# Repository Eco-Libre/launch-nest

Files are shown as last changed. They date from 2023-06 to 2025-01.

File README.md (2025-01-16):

# Eco-Libre Launch-Nest

This repo contains designs for a 5-story building that's designed to house 30 people in a small, off-grid community.

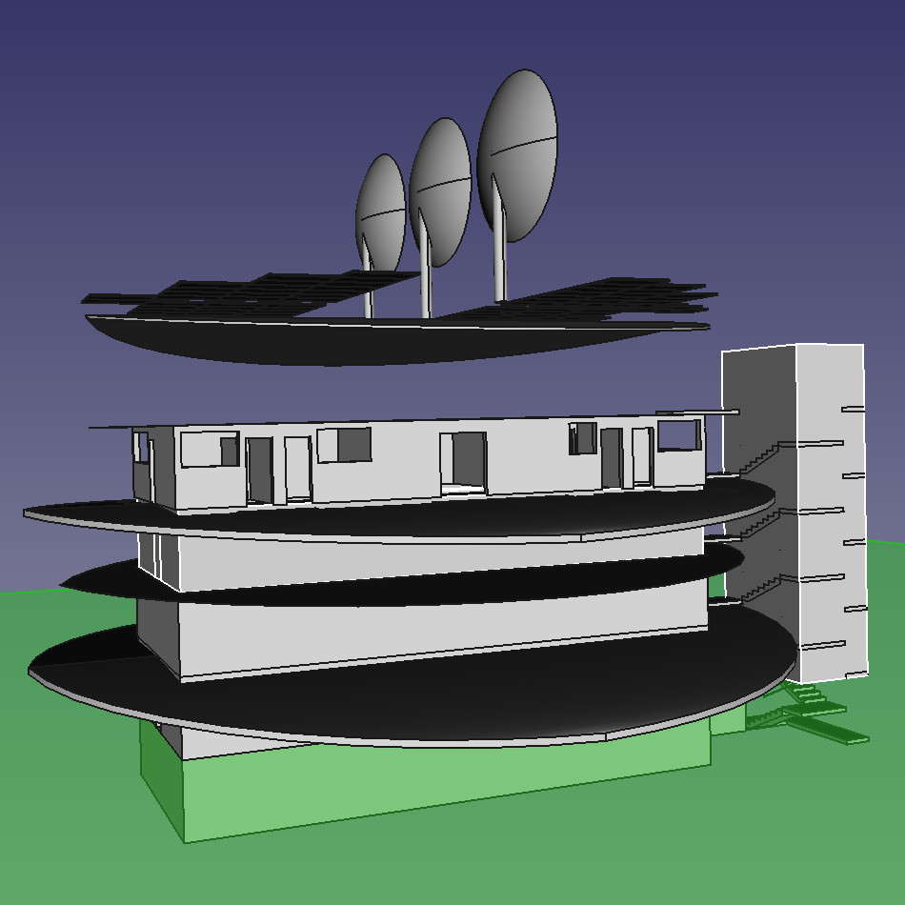
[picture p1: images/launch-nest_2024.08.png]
Screenshot of CAD file
</a>

The structure itself is 18 meters x 7 meters and has 5 stories of walled living space (630 sq meters). This does not include the solar energy rooftop, 5th floor terrace, wrap-around balcony, or firewalled stairwells.

## Basement

1. Food storage
1. Small urine sump tank & pump
1. Event Room (Theater, Presentation, Dance, Party, etc)
1. Recording Studio

## 1st Floor

1. Kitchen
1. Barrier-free bedroom (6 beds)
1. Shower room
1. Laundry Room
1. Medium-sized thermal salt tank
1. Large urine WC

## 2nd Floor

1. 2x Bedrooms (4 beds each = 8 people)
1. Ramp to terrace
1. Covered outdoor bicycle parking on terrace
1. Hot Water Tank (directly above showers)
1. Medium-sized thermal salt tank (next to hot water tank)
1. Small Urine WC
1. Telecommunications & Server Room
1. 1x meeting room
1. 1x large meeting room
1. Lockers and couches

## 3nd Floor

1. 2x Bedrooms (4 beds each = 8 people)
1. Large Urine WC
1. Library (~12 hot desks)
1. 2x Meeting Rooms

## 4th Floor

1. 2x Bedrooms (4 beds each = 8 people)
1. Small Urine WC
1. 1x Meeting Room
1. Indoor Coworking Space (~20 hot desks)
1. Snack and Coffee Bar
1. small-sized thermal salt tank

## 5th Floor

1. Open-Air Terrace
1. Projector & Presentation Space
1. Battery & Transformer Electrical Room
1. Large Thermal Salt Tank
1. Ground-Water Tank
1. Rain-Water Tank
1. Filtered Drinking-Water Tank
1. Primary Urine-Water Tank
1. Sun Room
1. Clothes Drying Area

## Rooftop

1. Parabolic Solar Concentrators
1. Solar Photovoltaic Array
1. Sloped, Steel-reinforced concrete grid
1. Sunroof grid
1. Large overhang of transparent polycarbonate panels
1. Small pressurized water tank (and pump) for washing solar equipment

# License

Copyright (C) 2023 Michael Altfield and the Eco-Libre Team

The contents of this repo are under the GPL version 3 or later.
In addition, any content other than code can also be used, at your
choice, under CC-BY-SA version 4.0.

This program is free software: you can redistribute it and/or modify
it under the terms of the GNU General Public License as published by
the Free Software Foundation, either version 3 of the License, or
(at your option) any later version.

This program is distributed in the hope that it will be useful,
but WITHOUT ANY WARRANTY; without even the implied warranty of
MERCHANTABILITY or FITNESS FOR A PARTICULAR PURPOSE.  See the
GNU General Public License for more details.

You should have received a copy of the GNU General Public License
along with this program.  If not, see <http://www.gnu.org/licenses/>.

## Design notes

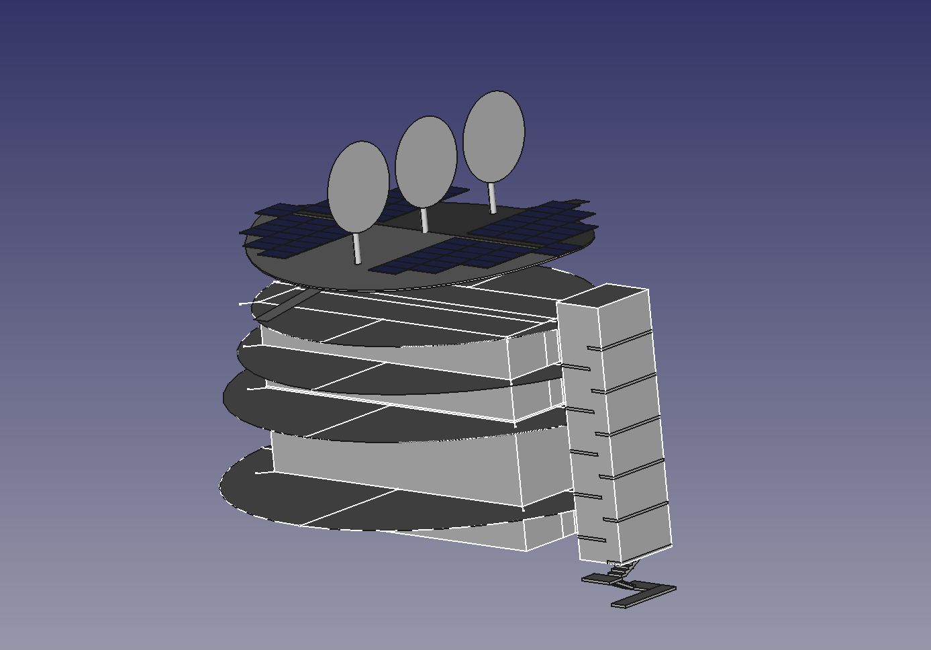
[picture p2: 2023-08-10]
images/launch-nest_2023.08.png

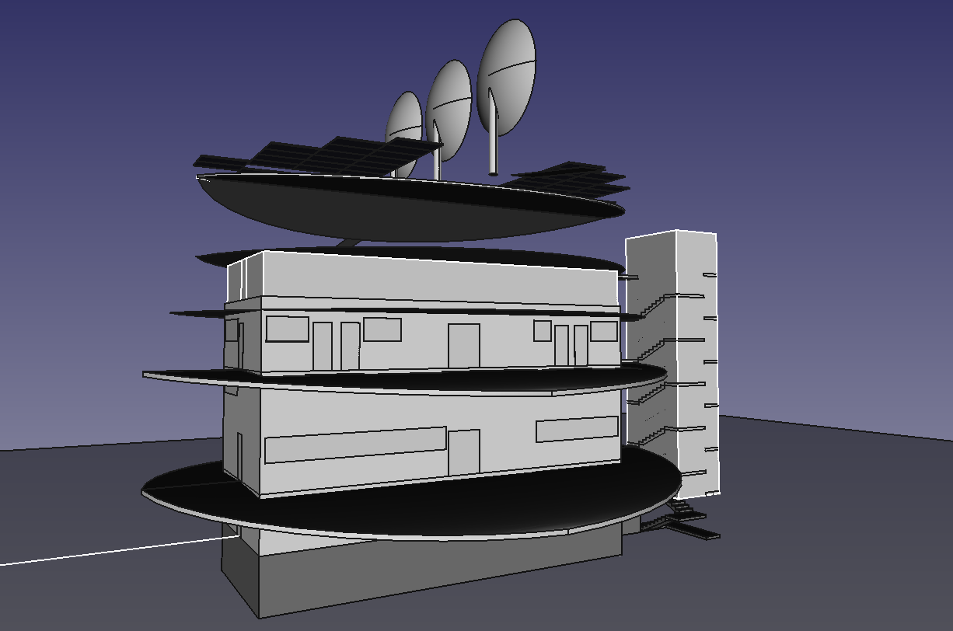
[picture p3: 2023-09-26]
images/launch-nest_2023.09.png

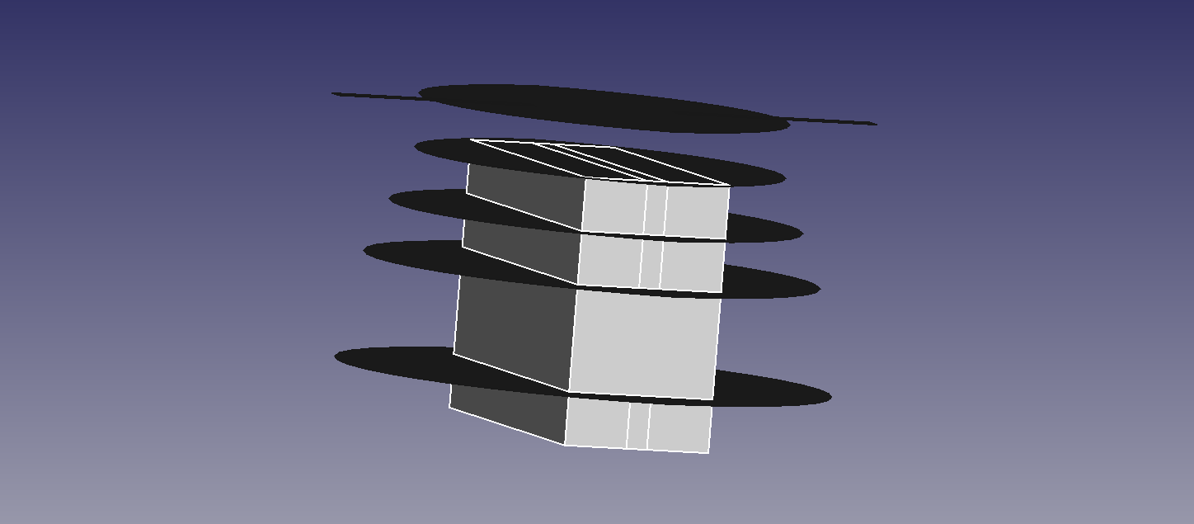
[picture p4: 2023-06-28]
images/launch-nest_2023.06.png

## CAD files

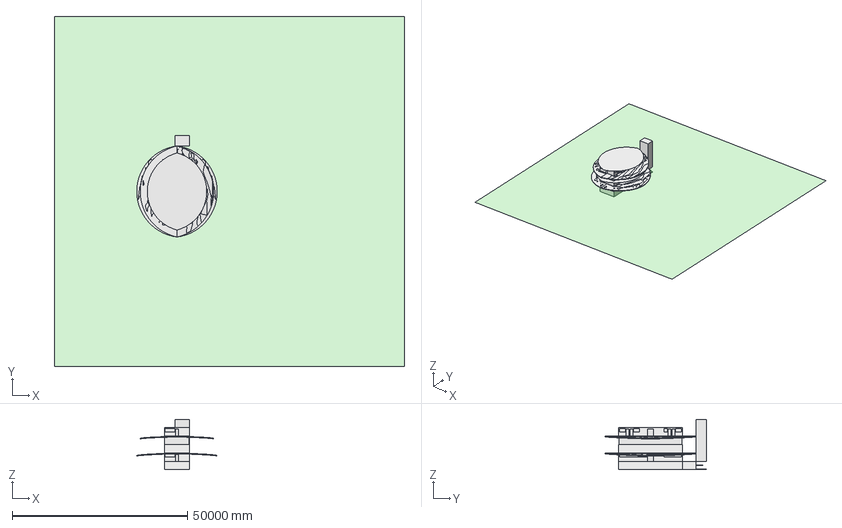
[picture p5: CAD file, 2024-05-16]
launch-nest.FCStd
100000.0 x 100000.0 x 14400.0 mm
floor 2 walls
left terrace surface 2
right terrace surface 2
left terrace
right terrace
floor 4 walls
right terrace surface 4
left terrace surface 4
left terrace 4
right terrace 4
floor 3
floor 3 terrace
floor 5 terrace
Wall
ground surface
rear stair landing
rear stair half landing
stairwell L-landing
rear stairwell exterior wall
rear door 1
front door 1
right door 1 main
left door 1 main
left window 1a
left window 1b
right window 1a
right window 1b
front widow 1
rear window 1
basement walls
rear door 4
front door 4
bedroom doors 4D
bedroom doors 4C
bedroom doors 4A
bedroom doors 4B
right door 4
left door 4
rear window 4
right window 4D
right window 4A
right window 4C
left window 4B
left window 4A
left window 4C
left window 4D
right window 4B
front window 4

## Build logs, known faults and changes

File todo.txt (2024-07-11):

TODO:

 * add "events" space to basement
   - delete two of the 6m x 3m rooms
   - one 6m x 3 room will be storage
   - one 6m x 3 room will be recording studio
   - get rid of the other 2 rooms (keep the two that are under the 1st floor bedroom)
   - this will provide a space for events with loud music that's underground, so it will muffle the noise

 * increase storey height
   - Noise isolation between floors can only achieve so much through thick concrete slabs. Specifically STS (airborne sound) can be dampened between floors with a thick slab, but IIC (impact sound) needs physical isolation. This means building a floor above the floor (eg a raised bamboo floor whoose posts sit on rubber (sound-isolation) footings on-top of the concrete floor slab.
    * See https://engineering.stackexchange.com/questions/60671/how-to-build-apartment-floors-ceilings-to-not-transfer-sound/60672
   - We need to figure-out the thickness of the concrete slab + the (bamboo?) floating floor above it + a buffer on the ceiling for piping, duct work, light fixtures, or a (sound isolation) drop-ceiling
    * See https://engineering.stackexchange.com/questions/60825/are-mutli-story-structure-slabs-poured-on-center
   - The minimum height of clearance from the top of the floating floor to the bottom of any ceiling infrastructure should be 2.4 meters. Currently the wall height of each storey is only 2.4 meters -- which doesn't even take into account the slab thickness. So we may end-up with 3-meter wall-height.

 * add stairwells on either side
    - I think I should make these entirely outside the existing structure, located on either end of the short sides of the structure. This will save space inside, be a safer fire exit, allow us to add an elevator on the outside along the stairwell, and it would allow us to re-use the same stairwell for the other buildings that would come perpendicular to this one
    - also, I think we should only have the stairwells go up to the 6th floor. We can have just a ladder and hatch to get from the 6th floor to the rooftop. This will reduce materials and prevent casting shade on our solar equipment on the rooftop

 * finish roof
    - make the steel-reinforced-concrete rooftop have a slight slope
    - add gutters
    - add transparent roofing around the perimeter
    - convert solid roof to grid of steel-reinforced concrete walkways
    - add parabolic dishes where the grid is
    - add transparent roofing where the gird is not

 * add different sizes

	Pico (6-person) (the smallest Eco-Libre Launch-Nest): it's just the basement and 1st floor, with ability to add another floor later

	Nano (14-person): Adds the second floor with two additional bedrooms

	Micro (30-person): Adds the rest of the structure

	Milli (150-person): Adds two more launch nests on either side, plus another two running parallel 60 meters away

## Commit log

2023-06-25 2023-06-25: After spending too much time dreaming and writing-out ideas in Zim, I'm finally creating the first "housing" structure in zim.
    In this first commit I've added a spreadsheet that determines the width and height and number of bedrooms. The idea is that it'll be shaped rectangular like an apartment. I don't want to make it wider because I want every room to have balcony access. The structure will grow to 6 stories, and if that's not enough, I'll add 3x more around a courtyard. Then that 4x design can be duplicated to form blocks and streets, if needed.
    Anyway, all I have now are the 4 external walls and a hallway. Now I need to add some room dividers. Then I want to experiment with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
    [house2.FCStd]
2023-06-27 fixed constraints on sketch and adjusted floor height to come from spreadsheet (with new alias for ceiling height)
    [house2.FCStd]
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2023-06-28 made the 5th floor and the terraces going-up slightly smaller
    I'm thinking that the actual roof of every terrace will be equal, but the floor will end shorter as it gets higher. The floor will be extended (after a railing) by transparent roofing. This will allow more light into the lower terraces without getting rain on the edges (where we may like to place tables & chairs)
    [house2.FCStd]
2023-06-28 added roof.
    Actually, I realized that I don't need clear roofing panels on every floor. I just need to have this last roof layer extend-out an overhang that's larger than the second-floor terrace. I don't think 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
    [house2.FCStd]
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2023-06-28 added a 1-meter-wide "roof walkway" I might remove this, instead opting for a smaller beam. Anyway, this currently shows how far out I plan to build the roof overhang that will use transparent roofin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
    [house2.FCStd]
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2023-06-28 began slicing-up the roof into triangles with the hope of making it sloped. First (North-West) triangle is done with this commit
    [launch-nest.FCStd]
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2023-06-28 created sketch of just NW roof triangle
    I couldn't find a way to go from a surface to a part. This is an issue because a surface doesn't appear to have a thickness and it can't be manipulated in three dimensions. I need one point of the triangle to be shifted-up in the z-plane
    [launch-nest.FCStd]
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2023-06-28 added last triangle, but it's shit
    I couldn't figure out how to draw a sketch in three dimensions. What I really need is to just move the vertex where all the triangeles meet up by, say, 0.5 meters. That's it. But all I could do was d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
    How the heck do I just modify the z-coordinates of one vertex in a sketch on the xy plane?
    [launch-nest.FCStd]
2023-06-28 tried a cone for the roof, but that won't work because the sides are uneven. I scraped the cone and the triangles. What I really need is a 4-sided tetrahedron (disphenoid)
    [launch-nest.FCStd]
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2023-06-29 added a ridgeline for the rooftop slope, which will have a 1 meter rise. Across a run of 17 meters / 2 = 8.5 meters, that's a 6.71 degree slope, which should be good
    [launch-nest.FCStd]
2023-06-29 ok, holy shit, I figured out how to sketch in 3 dimensions..sort-of
    This commit adds a sloped plane that runs from the previously flat rooftop floor up to a ridgeline that was floating 1 meters above it, straddling the center.
    Well, it's just a triangle for now because it was easier than an arch. I'll do the arch next.
    Basically the way this worked is that I took my existing sketch of the roottop floorplan on the xy plane, then I created a *new* sketch that hovered a single ridgeline *above* that one, also on the x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
    At this point, the new sketch on the xy plane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
    [launch-nest.FCStd]
2023-06-29 drafted a wire around the arch for the other side of the rooftop.
    I had to use the "upgrade" button to combine the arch and the ridgeline together. That worked, but for some reason it isn't filled-in like the triangle
    [launch-nest.FCStd]
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2023-06-29 added 315W 315W 315W 315W 315W 315W 315W 315W 315W 315W 315W 315W 315W 315W 315W 315W 315W 315W 315W 315W 315W 315W 315W 315W 315W 315W 315W 315W 315W 315W 315W 315W 315W 315W 315W 315W 315W 315W 315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
    [launch-nest.FCStd]
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2023-06-29 added 36x solar cells on the rear half of the roof. At 315W per panel, that's 1.11.340 kW. We can mirror these arrays on the front half of the roof for a total of 22.680 kW, which meets our target of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
    And there's still space in the middle of the roof for our solar concentrators. Hopefully we can fit four 16 sq meter scheffler dishes, which are 5 meter by 4 meter.
    * https://www.sciencedirect.com/science/article/abs/pii/S2451904918302634
    [launch-nest.FCStd]
2023-06-29 added solar concentrator, mirrored solar cells, and somehow lost one row of solar panels (?)
    [launch-nest.FCStd]
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2023-06-29 added the 16 square meter Scheffler concentrator. The size of the dish in freecad is 5 meters in diameter, but it should actually be 5 meters in one axis and 4 meters in another axis. So they're a bi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
    Obviously the focal point will be aimed at a collection chamber, which is absent. But this roughly shows us that we can fit three dishes. They'll shade the PV rays, but I don't see a way around that 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
    [launch-nest.FCStd]
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2023-06-29 added new sketch just for the roof perimeter based off of the main roof sketch, which we'll position on a different z-axis so we can draft support beams at a slope
    [launch-nest.FCStd]
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2023-06-29 lowered the roof overhang from the roof by 0.6 meters. This will give the slope 6.843 degrees on the 5 meter run and 7.595 degrees on the 4.5 meter run. That's slightly more than the rooftop, which h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
    [launch-nest.FCStd]
2023-06-29 added a line for the start of the roof's overhang walkway, so I can attach to it in draft workbench
    [launch-nest.FCStd]
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2023-06-30 added a single stair
    after some research, it looks like the Irish government defines the "optimum" emergency (fire) egress stairwells of having a width of 1 meter, a rise of 150 mm, and a going/run of 300mm.
    * https://www.gov.ie/pdf/?file=https://assets.gov.ie/100533/6926c022-4a80-4a05-8a55-dda6347bdaca.pdf#page=null
    * https://www.gov.scot/publications/building-standards-technical-handbook-2020-non-domestic/2-fire/2-9-escape/
    There should be two stairwells for each building (which will be used to access two buildings each). The stairswells will be fully enclosed (no windows) exterior structures (fire-safe) that connect to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
    [launch-nest.FCStd]
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2023-06-30 added stairs with arch workbench, but this time where the rails are set to move along with the parent object
    [launch-nest.FCStd]
2023-06-30 I can't get the landings to work right, so I'm going to just draw the landings and draft a wire between them, then use arch stairs to draw them
    [launch-nest.FCStd]
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2023-06-30 added stairs
    ok, I figured out the stairs. It can't all be one wire. Per the documentation:
    Draft Wires with two or more segments will be used to create landings. They must be on a plane parallel to the global XY plane. For example, select a U-shaped wire for a half-turn landing and an L-shaped wire for a corner landing.
    Draft Lines will be used to create flights.
    If the vertices of all lines and wires have correct Z coordinates, the created stairs will use this information.
    The base objects must be selected in the correct order starting with the bottom object.
    So basically I had to draw a "U" shaped wire around the perimeter of each landing and a distinct line between each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
    [launch-nest.FCStd]
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2023-07-01 ok, now I have the stairs perfect
    The problem was that I was setting the "tread depth enforce" to 300 mm. When I used the ruler, I saw that the "rise" was some fraction above 150 mm or something. It wasn't even and it was fucking everything up.
    I don't see a way to set the "going" to 300 mm, but it appears to determine that based on the rise and the line that you've drawn. So I moved the landing to where I expected it mathmatically (-500+2900=2400). That was ok, but off-by-one (I guess because we're using the landing itself as a step to save space). So I put it to 2100 m in the x-plane, drew a line from the top of the bottom landing (on-center) to the bottom of the next landing up (on-cente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
    [launch-nest.FCStd]
2023-07-01 drew all the arch stair lines from what I've now learned to be the correct placement (top of the landing block on-center to bottom of the next landing block going up, on-center)
    [launch-nest.FCStd]
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2023-07-01 added the rooftop of the second building (approx location by eye, not exact mathematically)
    While the rooftops don't collide, it does appear that the overhangs will. I guess it's ok if one overhang just stops-short where it would intersect the other.
    [launch-nest.FCStd]
2023-07-01 added a slab to connect the stairwell to the shorter terraces
    [launch-nest.FCStd]
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2023-08-11 added second window on left side.
    Note that this one is intentionally shorter (5 meters instead of 8 meters) because we want a 3-meter wide sheer wall that will go from the bottom to the top of this structure.
    TODO: The sheer wall on the opposite side will be staggered, per confined masonry recommendations.
    [launch-nest.FCStd]
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2023-08-11 added second external window on the first floor. note that it's staggered from the short window on the other side, so the sheer walls are staggered on opposite sides of the building (per confined-mas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
    [launch-nest.FCStd]
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2023-08-11 fixed window on the left side of the workshop garage door so that they don't intersect
    [launch-nest.FCStd]
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2023-08-15 created a clone of the second-floor terrace sketch, so now there's one "high" terrace sketch and one "low" terrace sketch. The difference is the z-plane.
    I decided to have a 3-5 degree pitch on all terraces. In the case of the second-floor terrace, it extends 8 meters out from the exterior walls + 3.5 meters across the short-side of the structure = 11.5 meters total run.
    If the rise (fall) of the terrace is 0.7 meters across that 11.5 meter run, it's a 3.483 degree slope that meets our requirements
    * https://www.omnicalculator.com/construction/roof-pitch
    Having a pitched slope entering a doorway is a problem, so to make a ramp with no steps across the doorway's entrance, I decided to dro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
    [launch-nest.FCStd]
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2023-08-18 I built a giant 99 meter high cube that's the exact width & height of the building's exterior walls. I'll use this to "cut" the center of the terrace away.
    But I realized that I have an issue: I think the terrace sags down in the middle where the "ridge line" should be. I think I actually do have to add a line along the top to prevent this
    [launch-nest.FCStd]
2023-08-18 I fixed the terrace "sag" by making it two surfaces that are bounded by a "ridge line" at the top sketch. Then I extruded it in the negative z axis 200 mm.
    Next I need to cut the giant cube out of it, so it isn't drawn inside the building
    [launch-nest.FCStd]
2023-08-18 I cut out the "center" of the terrace, which doesn't exist because that's inside the building
    [launch-nest.FCStd]
2023-08-18 I figured out how to fix the windows that have the red exclamation mark over it and the error `list index out of range Internal name: WindowXYZ`
    Traceback (most recent call last):
    File "/usr/share/freecad/Mod/Arch/ArchWindow.py", line 830, in execute
    shapes = self.buildShapes(obj)
    File "/usr/share/freecad/Mod/Arch/ArchWindow.py", line 631, in buildShapes
    wires.append(obj.Base.Shape.Wires[j])
    <class 'IndexError'>: list index out of range
    I had to edit the sketch and change the `Frame 2` & `Frame 3` from "0 mm" to "1 mm"
    For more info, see:
    * https://forum.freecad.org/viewtopic.php?p=700473#p700473
    [launch-nest.FCStd]
2023-08-18 Fixed all the remaining window errors by updating the value of h1 *after* the window was created to be non-zero by changing the `Frame 2` & `Frame 3` from "0 mm" to "1 mm"
    * https://github.com/yorikvanhavre/BIM_Workbench/issues/116
    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
    [launch-nest.FCStd]
2023-08-18 added interior walls to the 4th floor, which includes the 4x 3meter-by-3meter bedrooms and the common space in-between
    TODO: divide the common-space to add rooms for:
    1. Telecommunications & Server Room
    2. Storage Room
    3. Small Urine WC
    4. Laundry Room
    The Server Room needs to be secure, insulated, and Air Conditioned.
    The Storage Room should be secure, so it can be used to store some expensive items, if needed.
    The laundry room doesn't need to be secured, but we should put it in a thick-walled room with heavy doors to contain noise
    There will also been a "locker room," but this doesn't need to be in a room at all. Actually, it's better to have this in the open
    [launch-nest.FCStd]
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2023-08-19 converted floor #4's walls from extrusions to arch walls, but it looks like there's an issue with the sketch that needs to be addressed; some walls are missing..
    [launch-nest.FCStd]
2023-08-20 fixed the walls on the 4th floor
    Apparently there's a bug in FreeCAD where, if a sketch's lines overlap, the walls will be missing. So I deleted the 4th floor sketch and rebuilt it with shorter line segments.
    * https://github.com/FreeCAD/FreeCAD/issues/7370
    [launch-nest.FCStd]
2023-08-20 Added bedroom door
    I started working on the bedroom interior doors, but I realized there's four of them all in-a-row. So, instead of fighting with 4 distinct window elements, I just added one with a "depth" of 99 meters. That can be cleaned-up later, if needed.
    However, the door to the terrace on one of the bedrooms seems obstructed somehow. I saw this issue also when I was making individual doors. Not sure what's causing it.
    [launch-nest.FCStd]
2023-08-20 fixed last commit's window obstruction issue by deleting some orphaned windows
    [launch-nest.FCStd]
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2023-08-21 I'm going to commit before rolling-back and testing trying to fix the "T" issues that are breaking the creation of our extrusion/solid of the terrace cutout by using the "Toggle Construction Geometry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
    * https://forum.freecad.org/viewtopic.php?p=701082#p701082
    * https://wiki.freecad.org/Basic_Sketcher_Tutorial#Construction_geometry
    * https://wiki.freecad.org/Sketcher_ToggleConstruction
    [launch-nest.FCStd]
2023-08-21 I converted all of the internal reference lines that were creating "T" intersections of lines in the terrace cutaway sketch (that were causing the "wire not closed" error on extrusion and ultimately 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
    [launch-nest.FCStd]
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2023-08-21 I decided to have one accessible/barrier-free urine closet on every floor, but it takes-up about the entire size of one planned bathroom with many stalls.
    The ACA in the US seems to have accessible stalls that are 60 inches by 60 inches. Those are 1.5 meters x 1.5 meters. One of these takes up almost all of the space between the middle bedroom and the double-wide door in the common space between the bedrooms.
    [launch-nest.FCStd]
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2023-10-30 Updated TODO to include an event space in the basement
    While the 6th floor terrace is great for some events, I realized that some other types of events (eg parties with loud music) wouldn't be so nice for neighbors to be blasting noise from a rooftop high above the tree lines.
    Rather, let's reduce the store rooms in the basement from 3m x 6m down to 3m x 3m and replace two of the rooms with just one large open space. That'll give us 15m x 7 m = 105 square meters.
    According to the "4 sq meter rule", that will give us a capacity of 26.25 people. Our structure is built to sleep 30, so that's perfect. In fact, the "2-4 sq meter rule" is for comfortable corporate/private events. A dance party s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
2024-04-27 fixed the height of the 4th floor walls
    [launch-nest_simple.FCStd]
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2024-04-27 fixed stairs to only go to new terrace height
    [launch-nest_simple.FCStd]
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2024-05-16 getting rid of the six storey structure; replaced it with the five story structure
    [launch-nest.FCStd, launch-nest_simple.FCStd]
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2024-07-11 TODO: change height of each storey
    This commit updates the todo.txt file with some details about why we need to change the storey height.
    Currently we have 2.4 meters between each floor on-center, but that's with a 0-mm-thick concrete slab between each storey's walls. In reality, we need 2.4 meters of clearance between the top of the floor and the lowest point of the ceiling above (so including light fixtures, duct work, etc)
    But, since we set the height to 2.4 meters, I've also learned more about the sound transfer between floors. Previously I thought we could just have a very thick concrete slab, but it turns out that that won't prevent the transfer of impact noise between floors. So you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
2024-08-26 adding an svg "urban plan" file to map out how many launch nests fit together in an ideal landscape
    In this commit, I've created a file 'urban_plan.svg'. It's 2,000 cm x 2,000 cm. Each cm is supposed to represent 1 meter in real life.
    The launch nest has an external wall width of 18 meters, but when you include the terrace, it's 25 meters long. That doesn't include the stairwell, which adds another 3 meters.
    If we arrange 4 launch nests into a + shape, the width becomes <staircase> + <terrace> + <staircase> + <terrace> + <staircase>. That's 3 + 25 + 3 + 25 + 3 = 56 meters. But the actual structure will likely be longer, since we didn't account for the wall thickness in our original CAD des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
